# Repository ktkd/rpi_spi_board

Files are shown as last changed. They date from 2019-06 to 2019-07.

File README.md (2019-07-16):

# Orange pi spi board
KiCAD project with SPI NOR flash module (W25QXX DataFlash Board) for orange pi/raspberry pi

This board allow you to boot Orange PI directly from SPI Nor flash without SD card.

  for reference (http://linux-sunxi.org/Bootable_SPI_flash)

sunxi-fel output from orange pi pc and this board with 25q16 spi chip:
```
$ ./sunxi-fel spiflash-info
Manufacturer: Unknown (C8h), model: 40h, size: 2097152 bytes.
```

Components:
```
SPI flash SOIC-8 25 series (for examble 25q08 and above)
PLD-6 (DS1021-2x3S) 2.54mm (for jumper selector)
PBD-8 (DS1023 2x4) 2.54mm (for orange pi connector)
0805 resistor 10Ohm (for led)
0805 led 
```

connect board to red pins (pins 17-24 onboard SPI0)
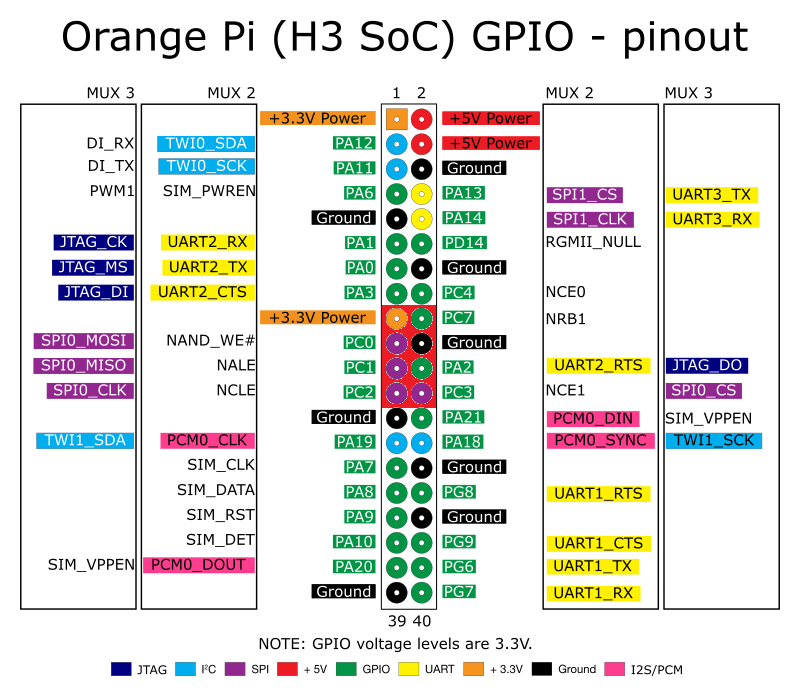
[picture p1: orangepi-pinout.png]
pinout


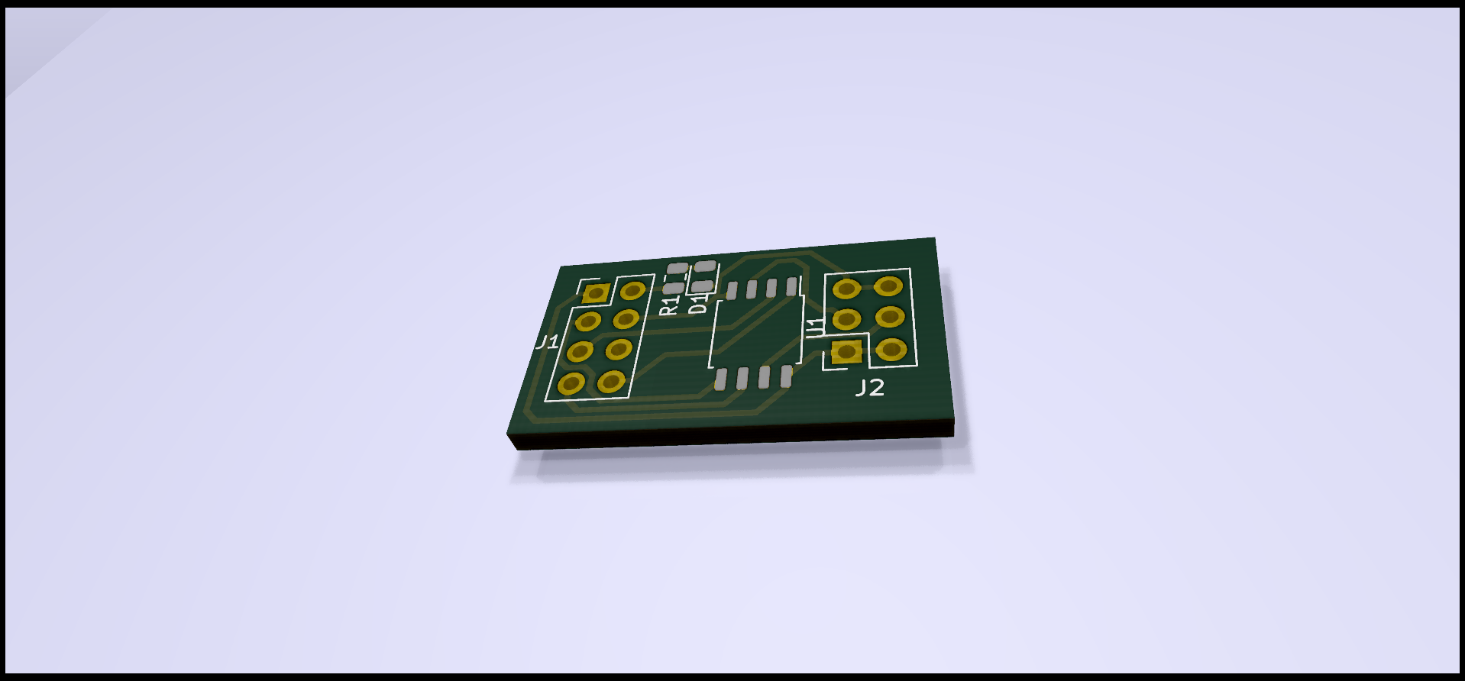
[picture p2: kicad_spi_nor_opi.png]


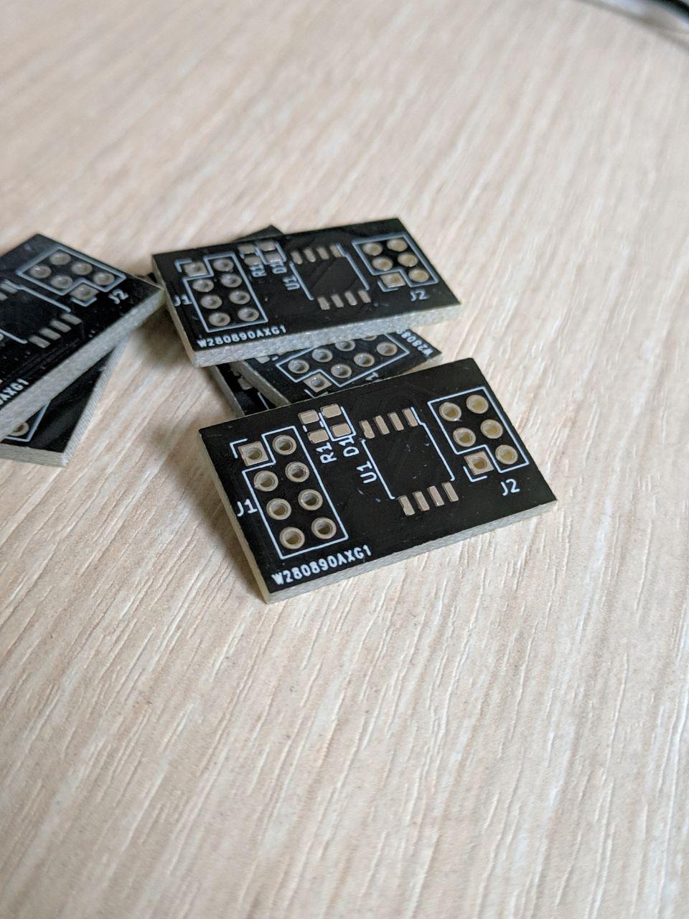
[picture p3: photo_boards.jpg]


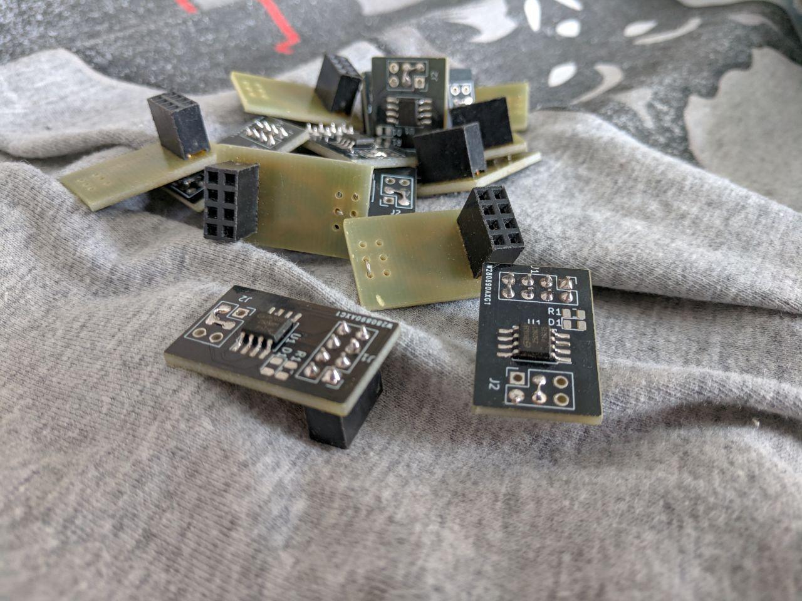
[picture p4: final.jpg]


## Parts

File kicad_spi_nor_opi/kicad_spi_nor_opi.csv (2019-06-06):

Id | Designator | Package | Quantity | Designation | Supplier and ref
1 | J2 | PinSocket_2x03_P2.54mm_Vertical | 1 | Jumper_wp/hold
2 | J1 | PinHeader_2x04_P2.54mm_Vertical | 1 | Opi_conn_1
3 | D1 | LED_0805_2012Metric | 1 | LED
4 | U1 | SOIC-8_5.23x5.23mm_P1.27mm | 1 | W25Qxxxx
5 | R1 | R_0805_2012Metric | 1 | R_Small

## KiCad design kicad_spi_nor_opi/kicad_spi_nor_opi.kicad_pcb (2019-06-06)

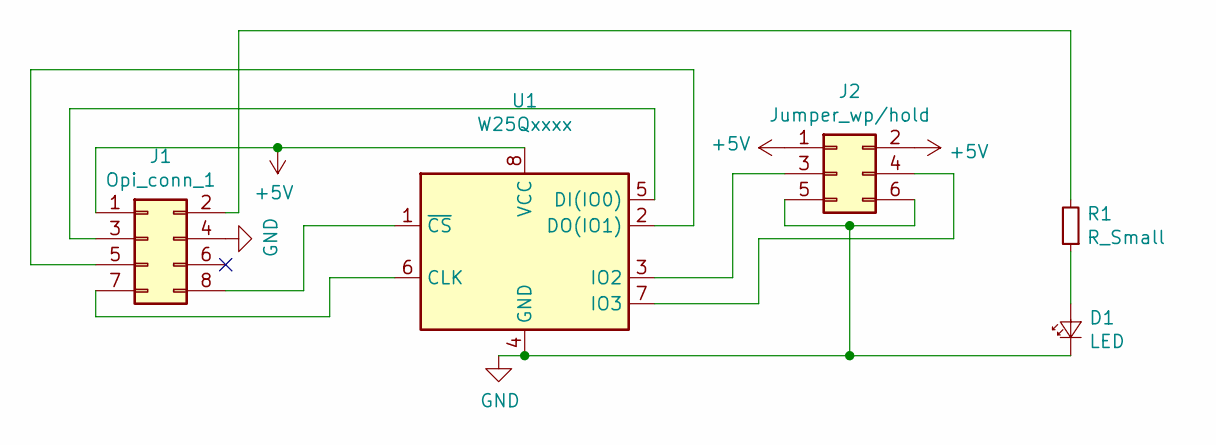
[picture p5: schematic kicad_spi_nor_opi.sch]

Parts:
D1: LED; LED_0805_2012Metric
J1: Opi_conn_1; PinHeader_2x04_P2.54mm_Vertical
J2: Jumper_wp/hold; PinSocket_2x03_P2.54mm_Vertical
R1: R_Small; R_0805_2012Metric
U1: W25Qxxxx; SOIC-8_5.23x5.23mm_P1.27mm

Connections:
+5V: J1.1, J2.1, J2.2, U1.8 (VCC)
GND: D1.1 (K), J1.4, J2.5, J2.6, U1.4 (GND)
unnamed: D1.2 (A), R1.1
unnamed: J1.2, R1.2
unnamed: J1.3, U1.5 (DI(IO0))
unnamed: J1.5, U1.2 (DO(IO1))
unnamed: J1.7, U1.6 (CLK)
unnamed: J1.8, U1.1 (~CS)
unnamed: J2.3, U1.3 (IO2)
unnamed: J2.4, U1.7 (IO3)

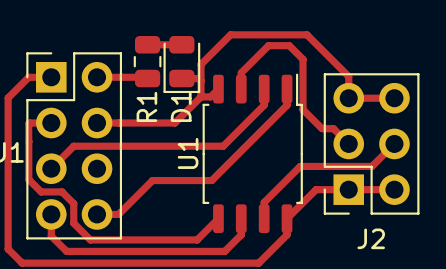
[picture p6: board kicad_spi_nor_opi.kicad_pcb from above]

Board: 2 copper layers, 5 parts (0 on the bottom side), 10 nets.

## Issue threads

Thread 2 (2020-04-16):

Add license information

vazhnov, 2020-04-16:
Hello!

Could you please add information about license — is it allowed to copy, change and use code in any purpose?
It would be great to see any popular open source license.

ktkd, 2020-05-23:
hello, sure you can use and modify this project files as you want.

vazhnov, 2020-05-24:
GPL 3 — wonderful! @ktkd, thank you!

Closed 2020-05-23.

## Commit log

2019-06-06 add description
    [kicad_spi_nor_opi.kicad_pcb, kicad_spi_nor_opi.sch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]
2019-06-06 pre print
    [kicad_spi_nor_opi-B_Adhes.gbr, kicad_spi_nor_opi-B_Cu.gbr, kicad_spi_nor_opi-B_Mask.gbr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]
2019-06-06 remove files
    [kicad_spi_nor_opi-B_Adhes.gbr, kicad_spi_nor_opi-B_Cu.gbr, kicad_spi_nor_opi-B_Mask.gbr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]
2019-11-10 Added gerbers to produce at jlcpcb factory
    [kicad_spi_nor_opi-B_Cu.gbl, kicad_spi_nor_opi-B_Mask.gbs, kicad_spi_nor_opi-B_SilkS.gbo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]
